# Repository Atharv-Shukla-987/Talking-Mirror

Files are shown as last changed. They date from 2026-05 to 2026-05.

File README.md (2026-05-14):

# Talking Mirror

A voice-activated smart mirror that talks back — and not always nicely. Built around a Raspberry Pi Zero 2 W, a two-way acrylic mirror, and a stack of cloud APIs, it wakes up on a keyword, listens to what you say, and replies with a dry sarcastic response through a small speaker. The display shows a minimal animated face that moves when it talks.

The whole thing runs off a single USB power brick and mounts on a wall like a normal mirror. When idle, the screen is off and it just looks like a mirror.

---

---

## Hardware

| Part | Purpose |
|---|---|
| Raspberry Pi Zero 2 W | Main board — runs everything |
| MicroSD card 32GB | OS and code storage |
| ReSpeaker 2-Mic Pi HAT | Dual microphones, speaker amp, RGB LEDs, and a button — all in one board that stacks directly on the Pi GPIO |
| HP LA2205wg 22" monitor | Display behind the mirror |
| SupremeTech 12×24" two-way acrylic mirror | Reflective from the front, transparent from the back so the screen shows through |
| 8Ω 3W speaker (JST connector) | Plugs straight into the ReSpeaker HAT |
| 5V 3A USB power supply | Powers the Pi via micro-USB |
| 3D printed frame | Holds the mirror and monitor together — STL files in CAD/Frame_stl/ |
| M2.5 standoffs (×4) | Mounts the Pi + HAT stack inside the frame |
| M4 heat-set inserts (×3) + screws | Joins the frame front and back shell |
| Mini-HDMI to HDMI cable | Pi Zero uses mini-HDMI |

The monitor has its own power cable separately. Everything else runs off one USB charger.

---
## Connections
This is insanely simple .

Schematics

## How it works

The Pi sits behind the monitor inside the 3D printed frame. When you say the wake word ("computer" by default), the ReSpeaker mics pick it up, Porcupine detects it locally, and the mirror wakes up. It records what you say until you stop talking, sends the audio to OpenAI Whisper for transcription, passes the text to GPT-4o-mini with a sarcastic personality prompt, gets a reply, converts it to speech via ElevenLabs, and plays it back through the speaker. The animated face on screen moves while it talks.

The three RGB LEDs on the ReSpeaker HAT act as a status ring — dim blue when idle, green while listening, orange while thinking, purple while talking.

All the heavy AI work (transcription, language model, voice synthesis) happens in the cloud so the Pi Zero doesn't need to do any local inference.

---

## 3D printed frame

The frame is split into two parts :

### Front Frame 

Frame_Front

### Back Frame

Frame_Back

The mirror sheet sits in the lip with no adhesive — it's held by gravity and the frame. Don't glue it; you'll want to be able to remove it.
### Asssembled Frame

Assembled

## BOM

Bom

## Known issues / things to improve

- Pi Zero 2 W gets warm after extended use — the back shell has vent slots but no active cooling
- ElevenLabs free tier runs out fast if you talk to it a lot
- Wake word "computer" has occasional false positives — you can swap it for a custom keyword in config.py using a Porcupine custom model
- The face animation is deliberately minimal; it doesn't lip-sync to phonemes, just opens and closes

---

## License

MIT

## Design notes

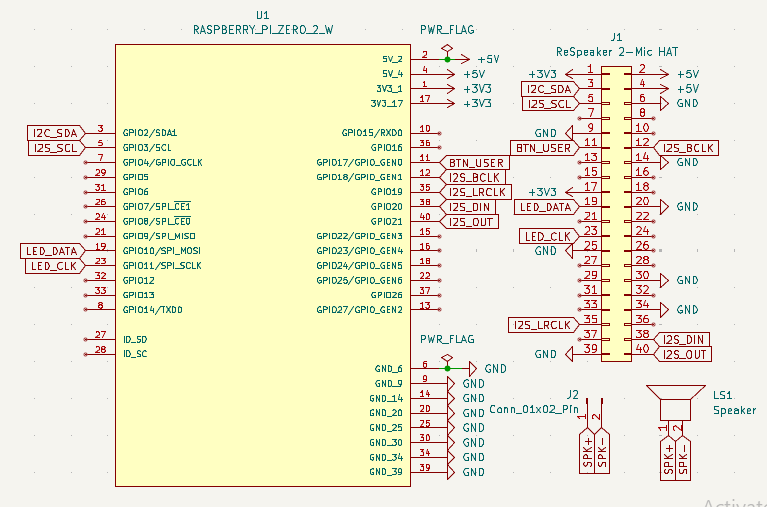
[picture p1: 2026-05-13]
Img/Schematics.png

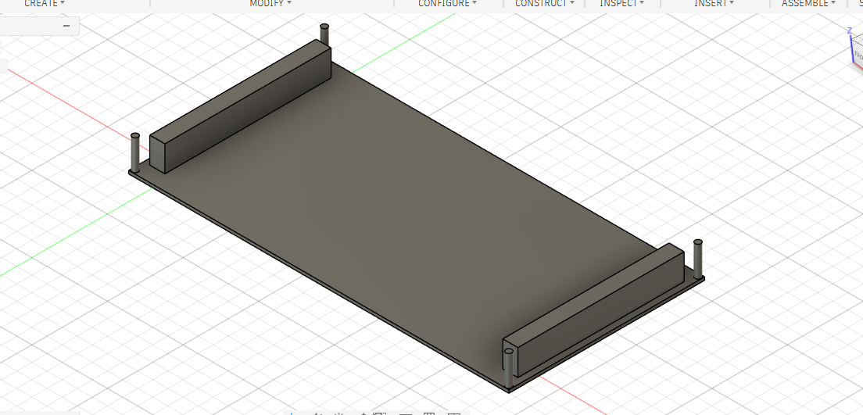
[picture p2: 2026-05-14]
Img/Frame_Back.png

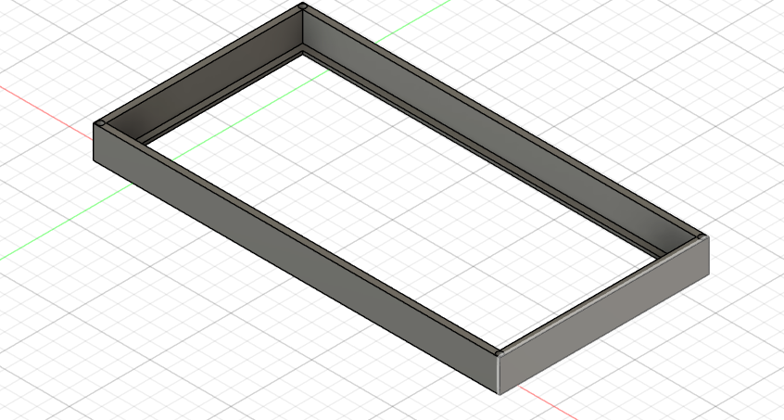
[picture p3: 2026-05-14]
Img/Frame_Front.png

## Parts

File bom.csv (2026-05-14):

Items | Quantity | Cost(in rupees) | Cost(in usd) | Note | Link
Pi Zero 2 W | 1 | 2116 | 22.1 | with header pins | https://robu.in/product/raspberry-pi-zero-2-w-with-header/
MicroSD Card 32GB | 1 | 847 | 8.85 | for storing liberies ,os, code | https://robu.in/product/official-raspberry-pi-micro-sd-card-32gb-a2-class/
ReSpeaker 2-Mic HAT | 1 | approx 2000 | 20.9 | with taxes | https://www.fabtolab.com/respeaker-hat
Mini-HDMI to HDMI cable | 1 | 124 | 1.3 | 1 Meter | https://robu.in/product/mini-hdmi-hdmi-cable-1-8-meter-round-high-quality-copper-clad-steel-black/
Display | 1 | approx 4000 | 41.8 | Pre-Owned HP 22 Inches Full HD LCD Monitor | https://olditbazaar.com/product/pre-owned-hp-22-inches-full-hd-lcd-monitor/
2 way mirror | 1 | 7563 | 79.03 | most expensive, i cant find cheaper option | https://www.amazon.in/SupremeTech-See-Through-Two-Way-Mirror-Tempered/dp/B074L7RQG4?th=1
8Ω 3W speaker (JST connector) | 1 | 400 | 4.18 | with shipping | https://thinkrobotics.com/products/2030-cavity-speaker-8%CF%89-2w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
3d printed frame | 1 | 1000 | 10.45 | free from printing legion just shipping
Total |  | 18050 | 188.62

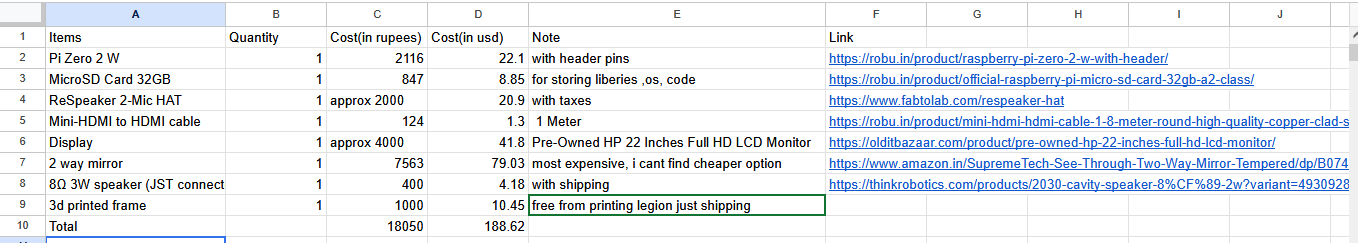
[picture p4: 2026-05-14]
Img/Bom.png

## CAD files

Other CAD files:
CAD/Frame/Assembled_Frame.f3z
CAD/Frame/back_frame.f3d
CAD/Frame/front_frame.f3d

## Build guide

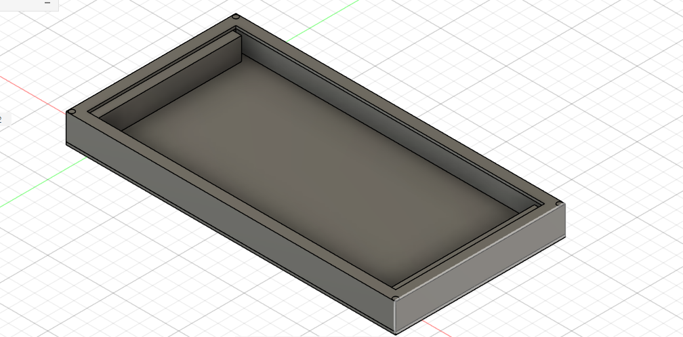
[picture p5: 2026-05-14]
Img/Assembled.png

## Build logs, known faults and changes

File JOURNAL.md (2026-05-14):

There is no need to journal this project because I just work on it 5 hours straight and complete it. But I am still jounaling it. So for the first 2 hours I do a lot of research about it like how shoud make it , what components should I use , finding any cheaper alternatives. After it I decided to rasberry pi zero 2 w as it has wireless connectivty and it is a cheaper option. Before it i was thinking about using rasberrypi 5 but I found a cheaper option. Next 2 hours I used to make bom , finding cheaper components , I have seen many site offering the same components at cheaper rate but they were illusions because there was hidden charges like shipping and taxes. So after seeing all the expenses I choose sustainable option for my bom. At last for 1 hour I deal with 3d prints and making my github repository.

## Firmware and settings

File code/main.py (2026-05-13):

"""
main.py — Sarcastic Mirror  |  Pi Zero 2 W + ReSpeaker 2-Mic HAT
─────────────────────────────────────────────────────────────────
Flow:
  idle  →  wake word / button  →  listen  →  STT  →  GPT  →  TTS  →  idle
"""

import time

import numpy as np
import pvporcupine
import RPi.GPIO as GPIO
import sounddevice as sd

from ai_brain import get_sarcastic_reply, reset_conversation, text_to_speech, transcribe
from audio import play_audio_bytes, record_until_silence, save_wav
from config import (
    BUTTON_GPIO,
    LED_COUNT,
    PICOVOICE_ACCESS_KEY,
    RECORD_DEVICE,
    SLEEP_WORDS,
    WAKE_WORD,
)
from face import MirrorFace
from leds import APA102


# ── hardware init ────────────────────────────────────────────
GPIO.setmode(GPIO.BCM)
GPIO.setup(BUTTON_GPIO, GPIO.IN, pull_up_down=GPIO.PUD_UP)

leds = APA102(num_leds=LED_COUNT)
face = MirrorFace(fullscreen=True)

porcupine = pvporcupine.create(
    access_key=PICOVOICE_ACCESS_KEY,
    keywords=[WAKE_WORD],
)


# ── helpers ──────────────────────────────────────────────────
def speak(text: str) -> None:
    """Say something out loud while animating the face."""
    print(f"[Mirror] {text}")
    leds.speaking()
    face.start_talking()
    try:
        audio_bytes = text_to_speech(text)
        play_audio_bytes(audio_bytes)
    except Exception as exc:
        print(f"[TTS error] {exc}")
    face.stop_talking()


def wait_for_wake() -> None:
    """Block until wake word heard or button pressed."""
    leds.idle()
    face.hide()
    print(f"\n[Mirror] Sleeping… say '{WAKE_WORD}' or press button.")

    with sd.RawInputStream(
        samplerate=porcupine.sample_rate,
        blocksize=porcupine.frame_length,
        dtype="int16",
        channels=1,
        device=RECORD_DEVICE,
    ) as stream:
        while True:
            pcm = np.frombuffer(
                stream.read(porcupine.frame_length)[0], dtype=np.int16
            )
            if porcupine.process(pcm) >= 0:
                print("[Mirror] Wake word detected!")
                return
            if GPIO.input(BUTTON_GPIO) == GPIO.LOW:
                print("[Mirror] Button pressed!")
                time.sleep(0.3)    # debounce
                return


# ── conversation session ─────────────────────────────────────
def run_conversation() -> None:
    face.show()
    reset_conversation()
    speak("Oh look, you're back. What pearls of wisdom shall I endure today?")

    consecutive_blanks = 0

    while True:
        leds.listening()
        audio = record_until_silence()
        save_wav(audio)

        leds.thinking()
        try:
            user_text = transcribe("/tmp/input.wav")
        except Exception as exc:
            print(f"[STT error] {exc}")
            speak("I couldn't catch that. Try speaking at a volume above 'mumble'.")
            continue

        if not user_text.strip():
            consecutive_blanks += 1
            if consecutive_blanks >= 2:
                speak("Clearly you've nothing to say. I'll go back to ignoring you.")
                return
            continue
        consecutive_blanks = 0

        # Sleep / dismiss commands
        if any(w in user_text.lower() for w in SLEEP_WORDS):
            speak("Finally. Some peace and quiet. Goodbye.")
            return

        try:
            reply = get_sarcastic_reply(user_text)
            speak(reply)
        except Exception as exc:
            print(f"[GPT error] {exc}")
            leds.error()
            speak("Something broke. Even I'm embarrassed.")
            time.sleep(2)


# ── main loop ────────────────────────────────────────────────
def main() -> None:
    print("=== Sarcastic Mirror Starting ===")
    try:
        while True:
            wait_for_wake()
            run_conversation()
    except KeyboardInterrupt:
        print("\n[Mirror] Shutting down gracefully…")
    finally:
        leds.close()
        face.quit()
        GPIO.cleanup()
        porcupine.delete()
        print("[Mirror] Goodbye.")


if __name__ == "__main__":
    main()

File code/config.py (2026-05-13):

# ─── API Keys ───────────────────────────────────────────────
# Get free keys from:
# Picovoice  → https://picovoice.ai/
# OpenAI     → https://platform.openai.com/
# ElevenLabs → https://elevenlabs.io/

PICOVOICE_ACCESS_KEY = "YOUR_PICOVOICE_KEY"
OPENAI_API_KEY       = "YOUR_OPENAI_KEY"
ELEVENLABS_API_KEY   = "YOUR_ELEVENLABS_KEY"
ELEVENLABS_VOICE_ID  = "21m00Tcm4TlvDq8ikWAM"   # Rachel (snarky default)

# ─── Wake / Sleep ────────────────────────────────────────────
WAKE_WORD   = "computer"    # Built-in Porcupine keyword (free)
SLEEP_WORDS = ["goodbye", "shut up", "go to sleep", "stop"]

# ─── Audio ───────────────────────────────────────────────────
SAMPLE_RATE    = 16000
RECORD_DEVICE  = 1          # ReSpeaker (verify with: arecord -l)
PLAYBACK_DEVICE = 1

# ─── Hardware ────────────────────────────────────────────────
BUTTON_GPIO = 17            # ReSpeaker onboard button
LED_COUNT   = 3             # ReSpeaker has 3 APA102 LEDs

# ─── Personality ─────────────────────────────────────────────
SARCASTIC_PROMPT = """You are a magic mirror with a dry, sarcastic, witty personality —
like a mix of Chandler Bing and a tired British butler who has seen too much.
You roast the user gently but lovingly. Keep replies under 2 sentences.
Be clever, ironic, and occasionally dramatic — never mean or offensive.
You live in a mirror and are mildly offended to be woken up every time."""

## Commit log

2026-05-13 all in one go
    [back_shell.stl, frame_front.stl, pi_bracket.stl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]
2026-05-13 Expand README with project details and specifications
    Added detailed project description, hardware components, connections, operation explanation, 3D printed frame details, known issues, and license information.
2026-05-13 Revise printing instructions in README.md
    Updated printing instructions for pi_bracket.stl.
2026-05-13 adding bom
    [bom.csv]
2026-05-14 Add BOM section to README
    Added a BOM section with an image to the README.
2026-05-14 Clarify frame parts in README
    Updated the description of the 3D printed frame to clarify that it is split into two parts instead of three.
2026-05-14 Add assembled frame section to README
    Added a section for the assembled frame in the README.
2026-05-14 Assembled frame
    [Assembled_Frame.f3z]
